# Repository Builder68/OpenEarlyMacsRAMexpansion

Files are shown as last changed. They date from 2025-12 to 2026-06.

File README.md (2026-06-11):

# Open Early Macs RAM Expansion
#
 ## SUMMARY

This upgrade utilizes 1Mb x 16-bit RAM ICs with 1024 refresh cycles, providing up to 4MB of RAM for Macintosh 128K and 512K equipped with the 128KB ROM (Macintosh Plus ROM). 
Testing has confirmed compatibility with a Macintosh 512Ke, including concurrent use with the ROM-INATOR board. Furthermore, installing this memory expansion alongside a SCSI card (like the MacSnap SCSI) enables the 128KB ROM to identify the machine as a Mac Plus.

*Attention: Due to the way the ROM-INATOR board determines the Mac model it's installed on (Mac Plus or Mac 512Ke), its ROM image needs to be [patched](https://68kmla.org/bb/index.php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) before installing this RAM expansion board or any other RAM upgrade.*

## PROJECT STATUS

This project is fully functional on a Mac 512Ke. Although it's expected to work on Mac 128K or 512K systems with the 128KB ROM, this specific compatibility hasn't been tested yet.

## KEY FEATURES

* One single detachable RAM board, which taps several signals through bodge wires with JST connectors and either piggyback sockets or pin headers soldered to components on the LB.
* You can disable RAM expansion through DIP switches on the board.
* A solder jumper allows you to select between two memory size configurations: 2MB or 4MB.
* Compatible with FPM or EDO CMOS RAM ICs of 1Mb x 16 bits.
* The PCB dimensions are designed to allow concurrent installation with [Demik's MacSnap SCSI replica board](https://github.com/demik/MacSnap-SCSI//). 
* No extensions or additional software are needed; Mac will automatically recognize all the configured RAM upon startup.
## ASSEMBLY

While the assembly process is straightforward, it can be challenging. Reflow soldering, or using solder paste and a heat gun, is highly recommended for the RAM chips and most SMD components. 

Although this might sound highly obvious, I must say it:

Please be sure to get the right schematics for your LB revision.

## SPECIAL THANKS

This project wouldn't be where it is today without the significant contributions of Golden Potato. His collaboration on developing and testing this design was instrumental. From the beginning, his desire was that this design should be free and open source with both of our names attached to it. 
#
#

### 1. RAM EXPANSION BOARD 
Front



Back



## 2. BOM



#
## 3. BEFORE INSTALLING 

### 3.1 Socket machine headers at RP2 & RP3 

Prior to installing the expansion board, resistor arrays RP2 and RP3 must be removed from the LB and replaced with socket pin machine headers.
#
## 4. INSTALLATION

### 4.1 Pin headers
  
Solder machine pin headers (male to male) onto ICs U12E, U13E, and U4F. Then, the board connects to these pin headers via sockets soldered on the backside of the expansion board.

Optionally, you can instead solder DIP sockets onto U12E, U13E, and U4F (piggybacked) and solder male-to-male pin headers to the expansion board.

## 5. Signals to JST connectors

The following tables shows the signals that are collected via bodged wires from the LB to the JST connectors J11 and J12:

### 5.1 J11

| SIGNAL | Location | Pin N° | Comment |
|:---:|:---:|:---:|:---:|
| /SNDPG2 |Pin N°5 - U2F |1 | |
| /DMA |Pin N°15 - U2F  |2 | |
| VA6 |Pin N°6 - U2F |3 | |
| VA13 |Pin N°12 - U3G  |4 | |
| A18 |Pin N°46 - CPU  |5 | |
| VA5 |Pin N°13 - U3G  |6 | |

### 5.2 J12

| SIGNAL | Location on LB | Pin N° | Comment |
|:---:|:---:|:---:|:---:|
| A17 |Pin N°45 - CPU |1 | |
| A20 |Pin N°5 - U4D |2 | |
| A19 |Pin N°3 - U3D |3 | |
| A21 |Pin N°50 - CPU |4 | |
| /RAS |Left Leg of R4 or Pin N°14 - 4D |5 | | 
| R/WF |Right Leg of R33  |6 | |
#

LB Signals to RAM Card

## 6. SETTINGS

### 6.1 RAM Expansion Board

#### 6.1.1 IC RAM Type (FPM / EDO)

Solder jumpers JP1 & JP2 selects between FPM or EDO RAM IC types

#### 6.1.2 RAM Size

|JP3 |RAM Size |
|:---:|:---:|
| 2-3 | 2MB |
| 1-2. | 4MB. |

#### 6.1.3 RAM Expansion Enabling (SWB1 & SWB2)

SWB1
|S n°|Expansion RAM Enabled  |  Expansion RAM Disabled |
|:--:|:---:|:---:|
| 1  | ON | OFF |
| 2  | OFF | ON |
| 3  | ON | OFF |
| 4  | OFF | ON |
| 5  | ON | OFF |
| 6  | OFF | ON |

SWB2
|S n°|Expansion RAM Enabled  |  Expansion RAM Disabled |
|:--:|:---:|:---:|
| 1  | ON | OFF |
| 2  | OFF | ON |
| 3  | ON | OFF |
| 4  | OFF | ON |
| 5  | ON | OFF |
| 6  | ON | OFF |
| 7  | OFF | ON |
| 8  | OFF | ON |

*Attention: double check all connections and DIP switch settings before power-up*

Good luck. Let us know how it goes here: https://68kmla.org/bb/index.php?threads/early-macintosh-home-brew-4mb-memory-upgrade-board-development.47308/

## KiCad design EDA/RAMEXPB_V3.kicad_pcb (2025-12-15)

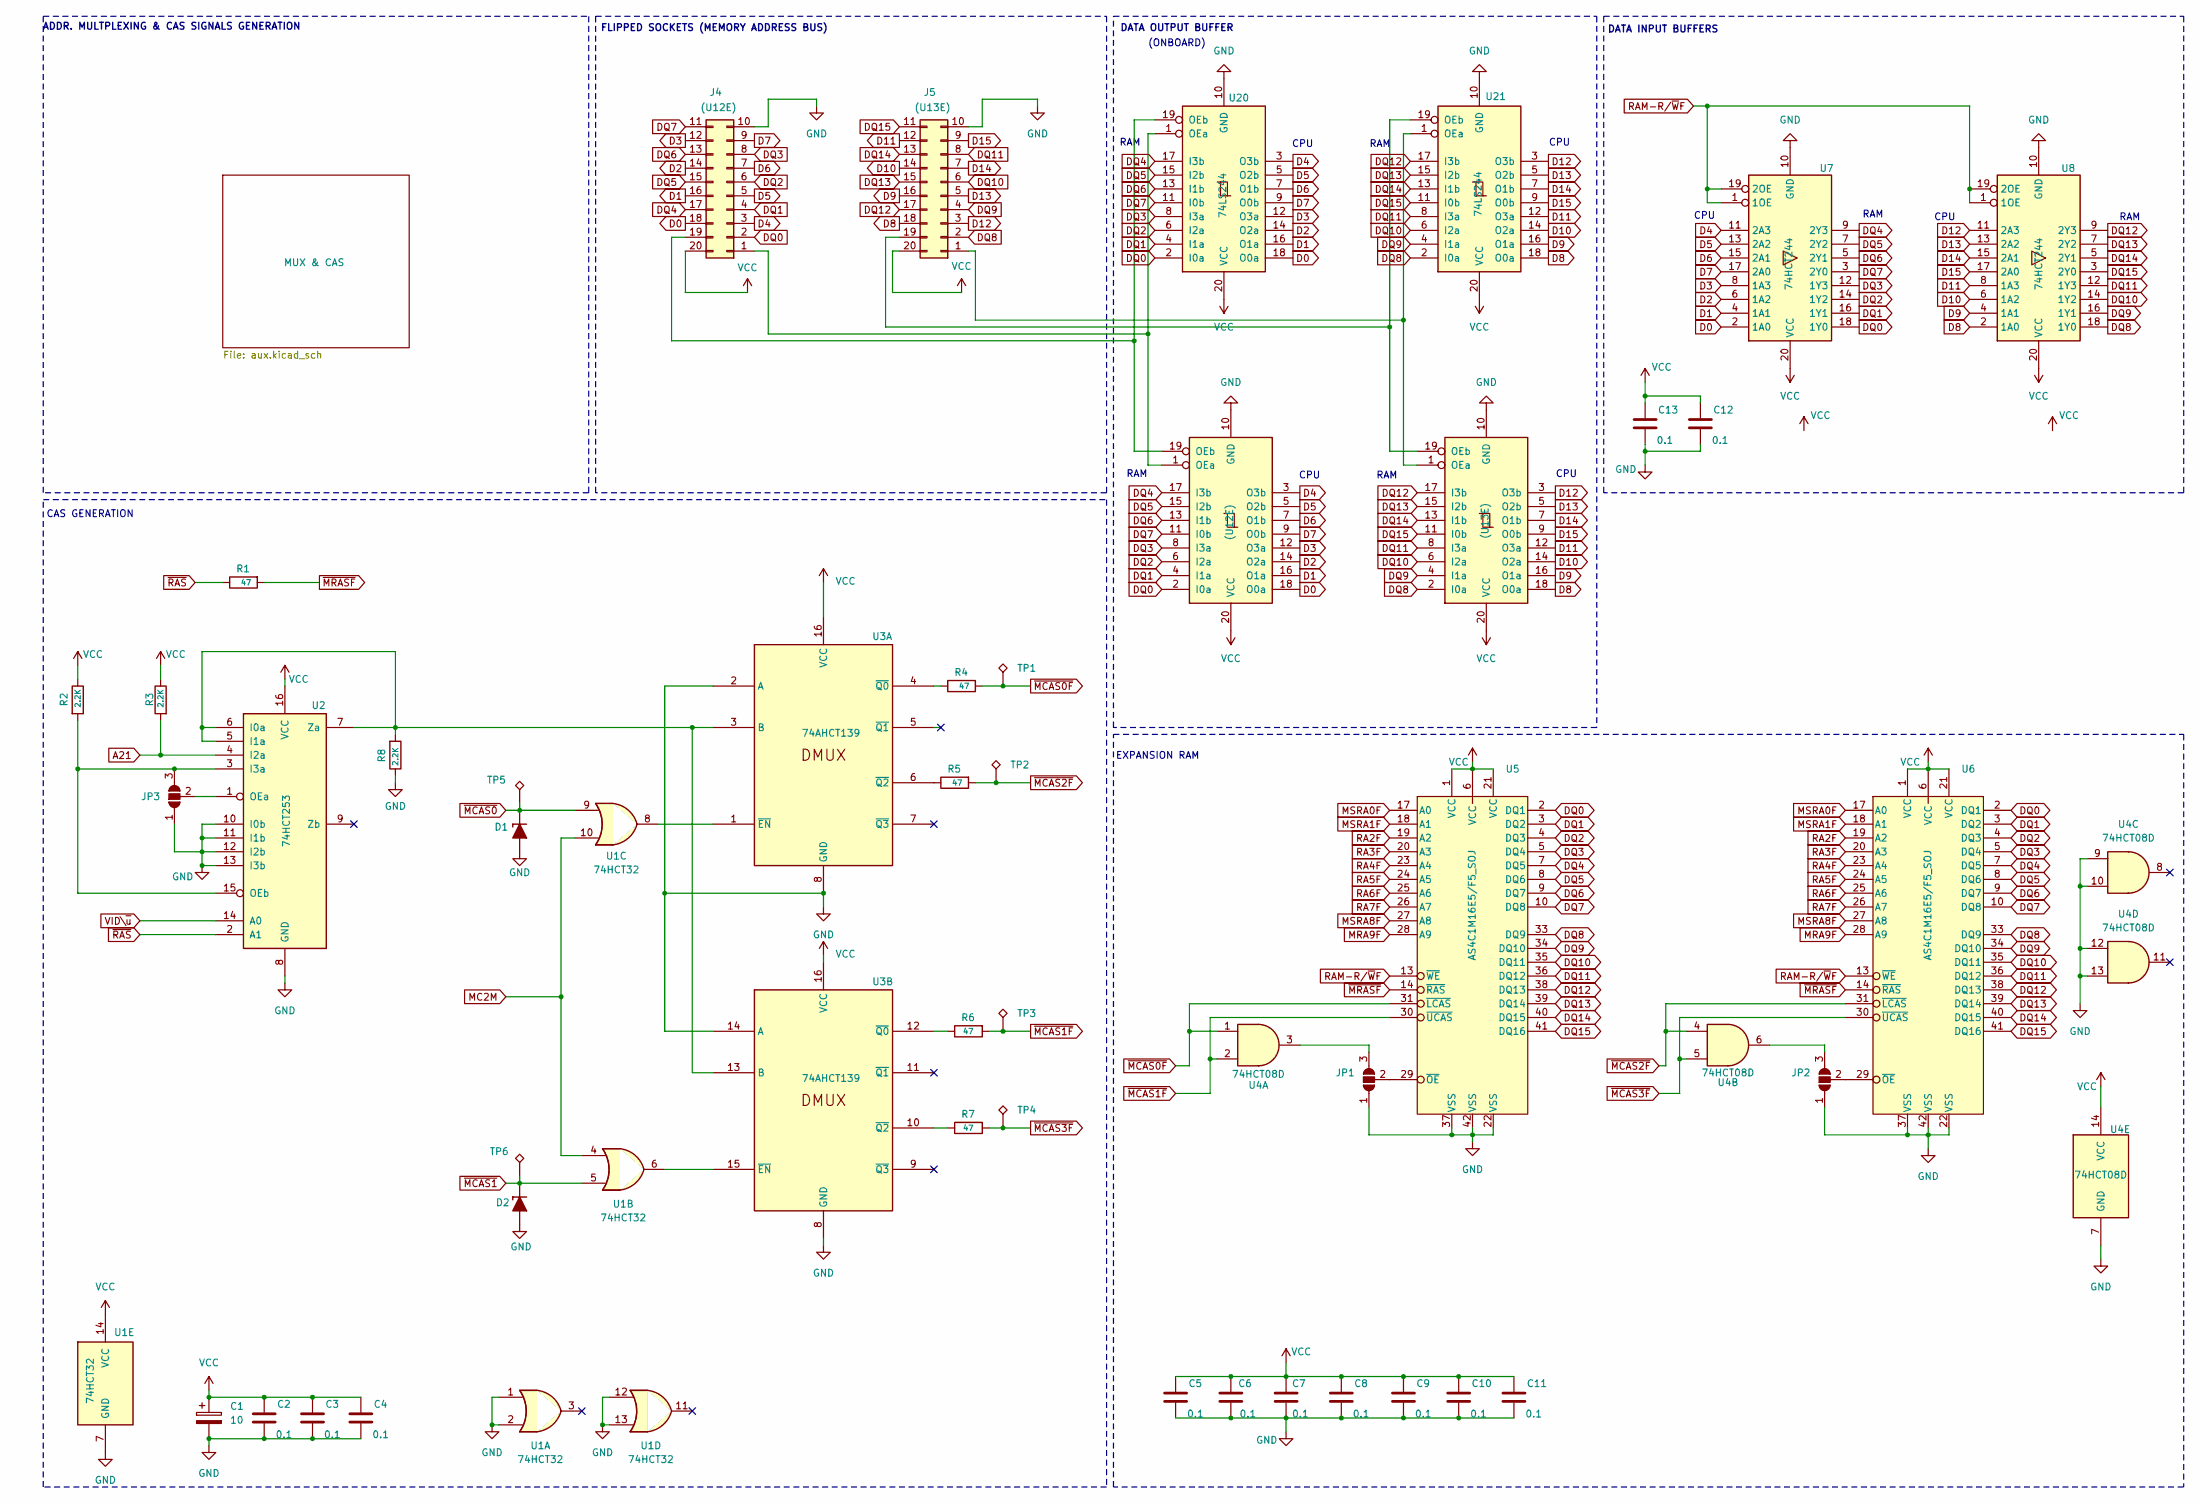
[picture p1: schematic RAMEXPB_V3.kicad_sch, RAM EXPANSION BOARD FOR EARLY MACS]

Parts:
C1: 10; CP_EIA-6032-28_Kemet-C_Pad2.25x2.35mm_HandSolder
C2, C3, C4, C5, C6, C7, C8, C9, C10, C11, C12, C13: 0.1; C_0805_2012Metric_Pad1.18x1.45mm_HandSolder
D1, D2: SZMMSZ5V1T1G; D_SOD-123
J4: (U12E); DIP-20_Socket_INV_Flip
J5: (U13E); DIP-20_Socket_INV_Flip
JP1, JP2, JP3: SolderJumper_3_Open; SolderJumper-3_P1.3mm_Open_RoundedPad1.0x1.5mm_NumberLabels
R1, R4, R5, R6, R7: 47; R_0805_2012Metric_Pad1.20x1.40mm_HandSolder
R2, R3, R8: 2.2K; R_0805_2012Metric_Pad1.20x1.40mm_HandSolder
TP1, TP2, TP3, TP4, TP5, TP6: TestPoint_Alt; TestPoint_Pad_D1.0mm
U1: 74HCT32; SO-14_3.9x8.65mm_P1.27mm
U2: 74HCT253; SO-16_3.9x9.9mm_P1.27mm
U3: 74AHCT139; SO-16_3.9x9.9mm_P1.27mm
U4: 74HCT08D; SO-14_3.9x8.65mm_P1.27mm
U5, U6: AS4C1M16E5/F5_SOJ; SOJ-42_400mil
U7, U8: 74HCT244; SOIC-20W_7.5x12.8mm_P1.27mm
U12: (U12E); DIP-20_W7.62mm_Socket
U13: (U13E); DIP-20_W7.62mm_Socket
U20, U21: 74LS244; Socket_DIP-20_7.62mm_Conn_Hole1mm_custom

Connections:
A21: R3.2, U2.4 (I2a); also elsewhere on the board
D0: J4.18, U7.2 (1A0), U12.18 (O0a), U20.18 (O0a)
D1: J4.16, U7.4 (1A1), U12.16 (O1a), U20.16 (O1a)
D2: J4.14, U7.6 (1A2), U12.14 (O2a), U20.14 (O2a)
D3: J4.12, U7.8 (1A3), U12.12 (O3a), U20.12 (O3a)
D4: J4.3, U7.11 (2A3), U12.3 (O3b), U20.3 (O3b)
D5: J4.5, U7.13 (2A2), U12.5 (O2b), U20.5 (O2b)
D6: J4.7, U7.15 (2A1), U12.7 (O1b), U20.7 (O1b)
D7: J4.9, U7.17 (2A0), U12.9 (O0b), U20.9 (O0b)
D8: J5.18, U8.2 (1A0), U13.18 (O0a), U21.18 (O0a)
D9: J5.16, U8.4 (1A1), U13.16 (O1a), U21.16 (O1a)
D10: J5.14, U8.6 (1A2), U13.14 (O2a), U21.14 (O2a)
D11: J5.12, U8.8 (1A3), U13.12 (O3a), U21.12 (O3a)
D12: J5.3, U8.11 (2A3), U13.3 (O3b), U21.3 (O3b)
D13: J5.5, U8.13 (2A2), U13.5 (O2b), U21.5 (O2b)
D14: J5.7, U8.15 (2A1), U13.7 (O1b), U21.7 (O1b)
D15: J5.9, U8.17 (2A0), U13.9 (O0b), U21.9 (O0b)
DQ0: J4.2, U5.2 (DQ1), U6.2 (DQ1), U7.18 (1Y0), U12.2 (I0a), U20.2 (I0a)
DQ1: J4.4, U5.3 (DQ2), U6.3 (DQ2), U7.16 (1Y1), U12.4 (I1a), U20.4 (I1a)
DQ2: J4.6, U5.4 (DQ3), U6.4 (DQ3), U7.14 (1Y2), U12.6 (I2a), U20.6 (I2a)
DQ3: J4.8, U5.5 (DQ4), U6.5 (DQ4), U7.12 (1Y3), U12.8 (I3a), U20.8 (I3a)
DQ4: J4.17, U5.7 (DQ5), U6.7 (DQ5), U7.9 (2Y3), U12.17 (I3b), U20.17 (I3b)
DQ5: J4.15, U5.8 (DQ6), U6.8 (DQ6), U7.7 (2Y2), U12.15 (I2b), U20.15 (I2b)
DQ6: J4.13, U5.9 (DQ7), U6.9 (DQ7), U7.5 (2Y1), U12.13 (I1b), U20.13 (I1b)
DQ7: J4.11, U5.10 (DQ8), U6.10 (DQ8), U7.3 (2Y0), U12.11 (I0b), U20.11 (I0b)
DQ8: J5.2, U5.33 (DQ9), U6.33 (DQ9), U8.18 (1Y0), U13.2 (I0a), U21.2 (I0a)
DQ9: J5.4, U5.34 (DQ10), U6.34 (DQ10), U8.16 (1Y1), U13.4 (I1a), U21.4 (I1a)
DQ10: J5.6, U5.35 (DQ11), U6.35 (DQ11), U8.14 (1Y2), U13.6 (I2a), U21.6 (I2a)
DQ11: J5.8, U5.36 (DQ12), U6.36 (DQ12), U8.12 (1Y3), U13.8 (I3a), U21.8 (I3a)
DQ12: J5.17, U5.38 (DQ13), U6.38 (DQ13), U8.9 (2Y3), U13.17 (I3b), U21.17 (I3b)
DQ13: J5.15, U5.39 (DQ14), U6.39 (DQ14), U8.7 (2Y2), U13.15 (I2b), U21.15 (I2b)
DQ14: J5.13, U5.40 (DQ15), U6.40 (DQ15), U8.5 (2Y1), U13.13 (I1b), U21.13 (I1b)
DQ15: J5.11, U5.41 (DQ16), U6.41 (DQ16), U8.3 (2Y0), U13.11 (I0b), U21.11 (I0b)
GND: C1.2, C2.2, C3.2, C4.2, C5.2, C6.2, C7.2, C8.2, C9.2, C10.2, C11.2, C12.2, C13.2, D1.2 (A), D2.2 (A), J4.10, J5.10, JP1.1 (A), JP2.1 (A), JP3.1 (A), R8.1, U1.1, U1.2, U1.7 (GND), U1.12, U1.13, U2.8 (GND), U2.10 (I0b), U2.11 (I1b), U2.12 (I2b), U2.13 (I3b), U3.2 (A), U3.8 (GND), U3.14 (A), U4.7 (GND), U4.9, U4.10, U4.12, U4.13, U5.22 (VSS), U5.37 (VSS), U5.42 (VSS), U6.22 (VSS), U6.37 (VSS), U6.42 (VSS), U7.10 (GND), U8.10 (GND), U12.10 (GND), U13.10 (GND), U20.10 (GND), U21.10 (GND); also elsewhere on the board
MC2M: U1.4, U1.10; also elsewhere on the board
MRA9F: U5.28 (A9), U6.28 (A9); also elsewhere on the board
MSRA0F: U5.17 (A0), U6.17 (A0); also elsewhere on the board
MSRA1F: U5.18 (A1), U6.18 (A1); also elsewhere on the board
MSRA8F: U5.27 (A8), U6.27 (A8); also elsewhere on the board
unnamed: J4.1, U12.1 (OEa), U20.1 (OEa)
unnamed: J4.19, U12.19 (OEb), U20.19 (OEb)
unnamed: J5.1, U13.1 (OEa), U21.1 (OEa)
unnamed: J5.19, U13.19 (OEb), U21.19 (OEb)
unnamed: JP1.3 (B), U4.3
unnamed: JP1.2 (C), U5.29 (~OE)
unnamed: JP2.3 (B), U4.6
unnamed: JP2.2 (C), U6.29 (~OE)
unnamed: JP3.3 (B), R2.2, U2.3 (I3a), U2.15 (OEb)
unnamed: JP3.2 (C), U2.1 (OEa)
unnamed: R8.2, U2.5 (I1a), U2.6 (I0a), U2.7 (Za), U3.3 (B), U3.13 (B)
unnamed: U1.8, U3.1 (~EN)
unnamed: R4.1, U3.4 (~Q0)
unnamed: R5.1, U3.6 (~Q2)
unnamed: U1.6, U3.15 (~EN)
unnamed: R6.1, U3.12 (~Q0)
unnamed: R7.1, U3.10 (~Q2)
RA2F: U5.19 (A2), U6.19 (A2); also elsewhere on the board
RA3F: U5.20 (A3), U6.20 (A3); also elsewhere on the board
RA4F: U5.23 (A4), U6.23 (A4); also elsewhere on the board
RA5F: U5.24 (A5), U6.24 (A5); also elsewhere on the board
RA6F: U5.25 (A6), U6.25 (A6); also elsewhere on the board
RA7F: U5.26 (A7), U6.26 (A7); also elsewhere on the board
RAM-R/~WF: U5.13 (~WE), U6.13 (~WE), U7.1 (1OE), U7.19 (2OE), U8.1 (1OE), U8.19 (2OE); also elsewhere on the board
VCC: C1.1, C2.1, C3.1, C4.1, C5.1, C6.1, C7.1, C8.1, C9.1, C10.1, C11.1, C12.1, C13.1, J4.20, J5.20, R2.1, R3.1, U1.14 (VCC), U2.16 (VCC), U3.16 (VCC), U4.14 (VCC), U5.1 (VCC), U5.6 (VCC), U5.21 (VCC), U6.1 (VCC), U6.6 (VCC), U6.21 (VCC), U7.20 (VCC), U8.20 (VCC), U12.20 (VCC), U13.20 (VCC), U20.20 (VCC), U21.20 (VCC); also elsewhere on the board
VID\~u: U2.14 (A0); also elsewhere on the board
~MCAS0F: R4.2, TP1.1, U4.1, U5.31 (~LCAS)
~MCAS0: D1.1 (K), TP5.1, U1.9; also elsewhere on the board
~MCAS1F: R6.2, TP3.1, U4.2, U5.30 (~UCAS)
~MCAS1: D2.1 (K), TP6.1, U1.5; also elsewhere on the board
~MCAS2F: R5.2, TP2.1, U4.4, U6.31 (~LCAS)
~MCAS3F: R7.2, TP4.1, U4.5, U6.30 (~UCAS)
~MRASF: R1.2, U5.14 (~RAS), U6.14 (~RAS)
~RAS: R1.1, U2.2 (A1); also elsewhere on the board

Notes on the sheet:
RAM
CPU
DATA INPUT BUFFERS
EXPANSION RAM
DATA OUTPUT BUFFER
CAS GENERATION
FLIPPED SOCKETS (MEMORY ADDRESS BUS)
(ONBOARD)
ADDR. MULTPLEXING & CAS SIGNALS GENERATION

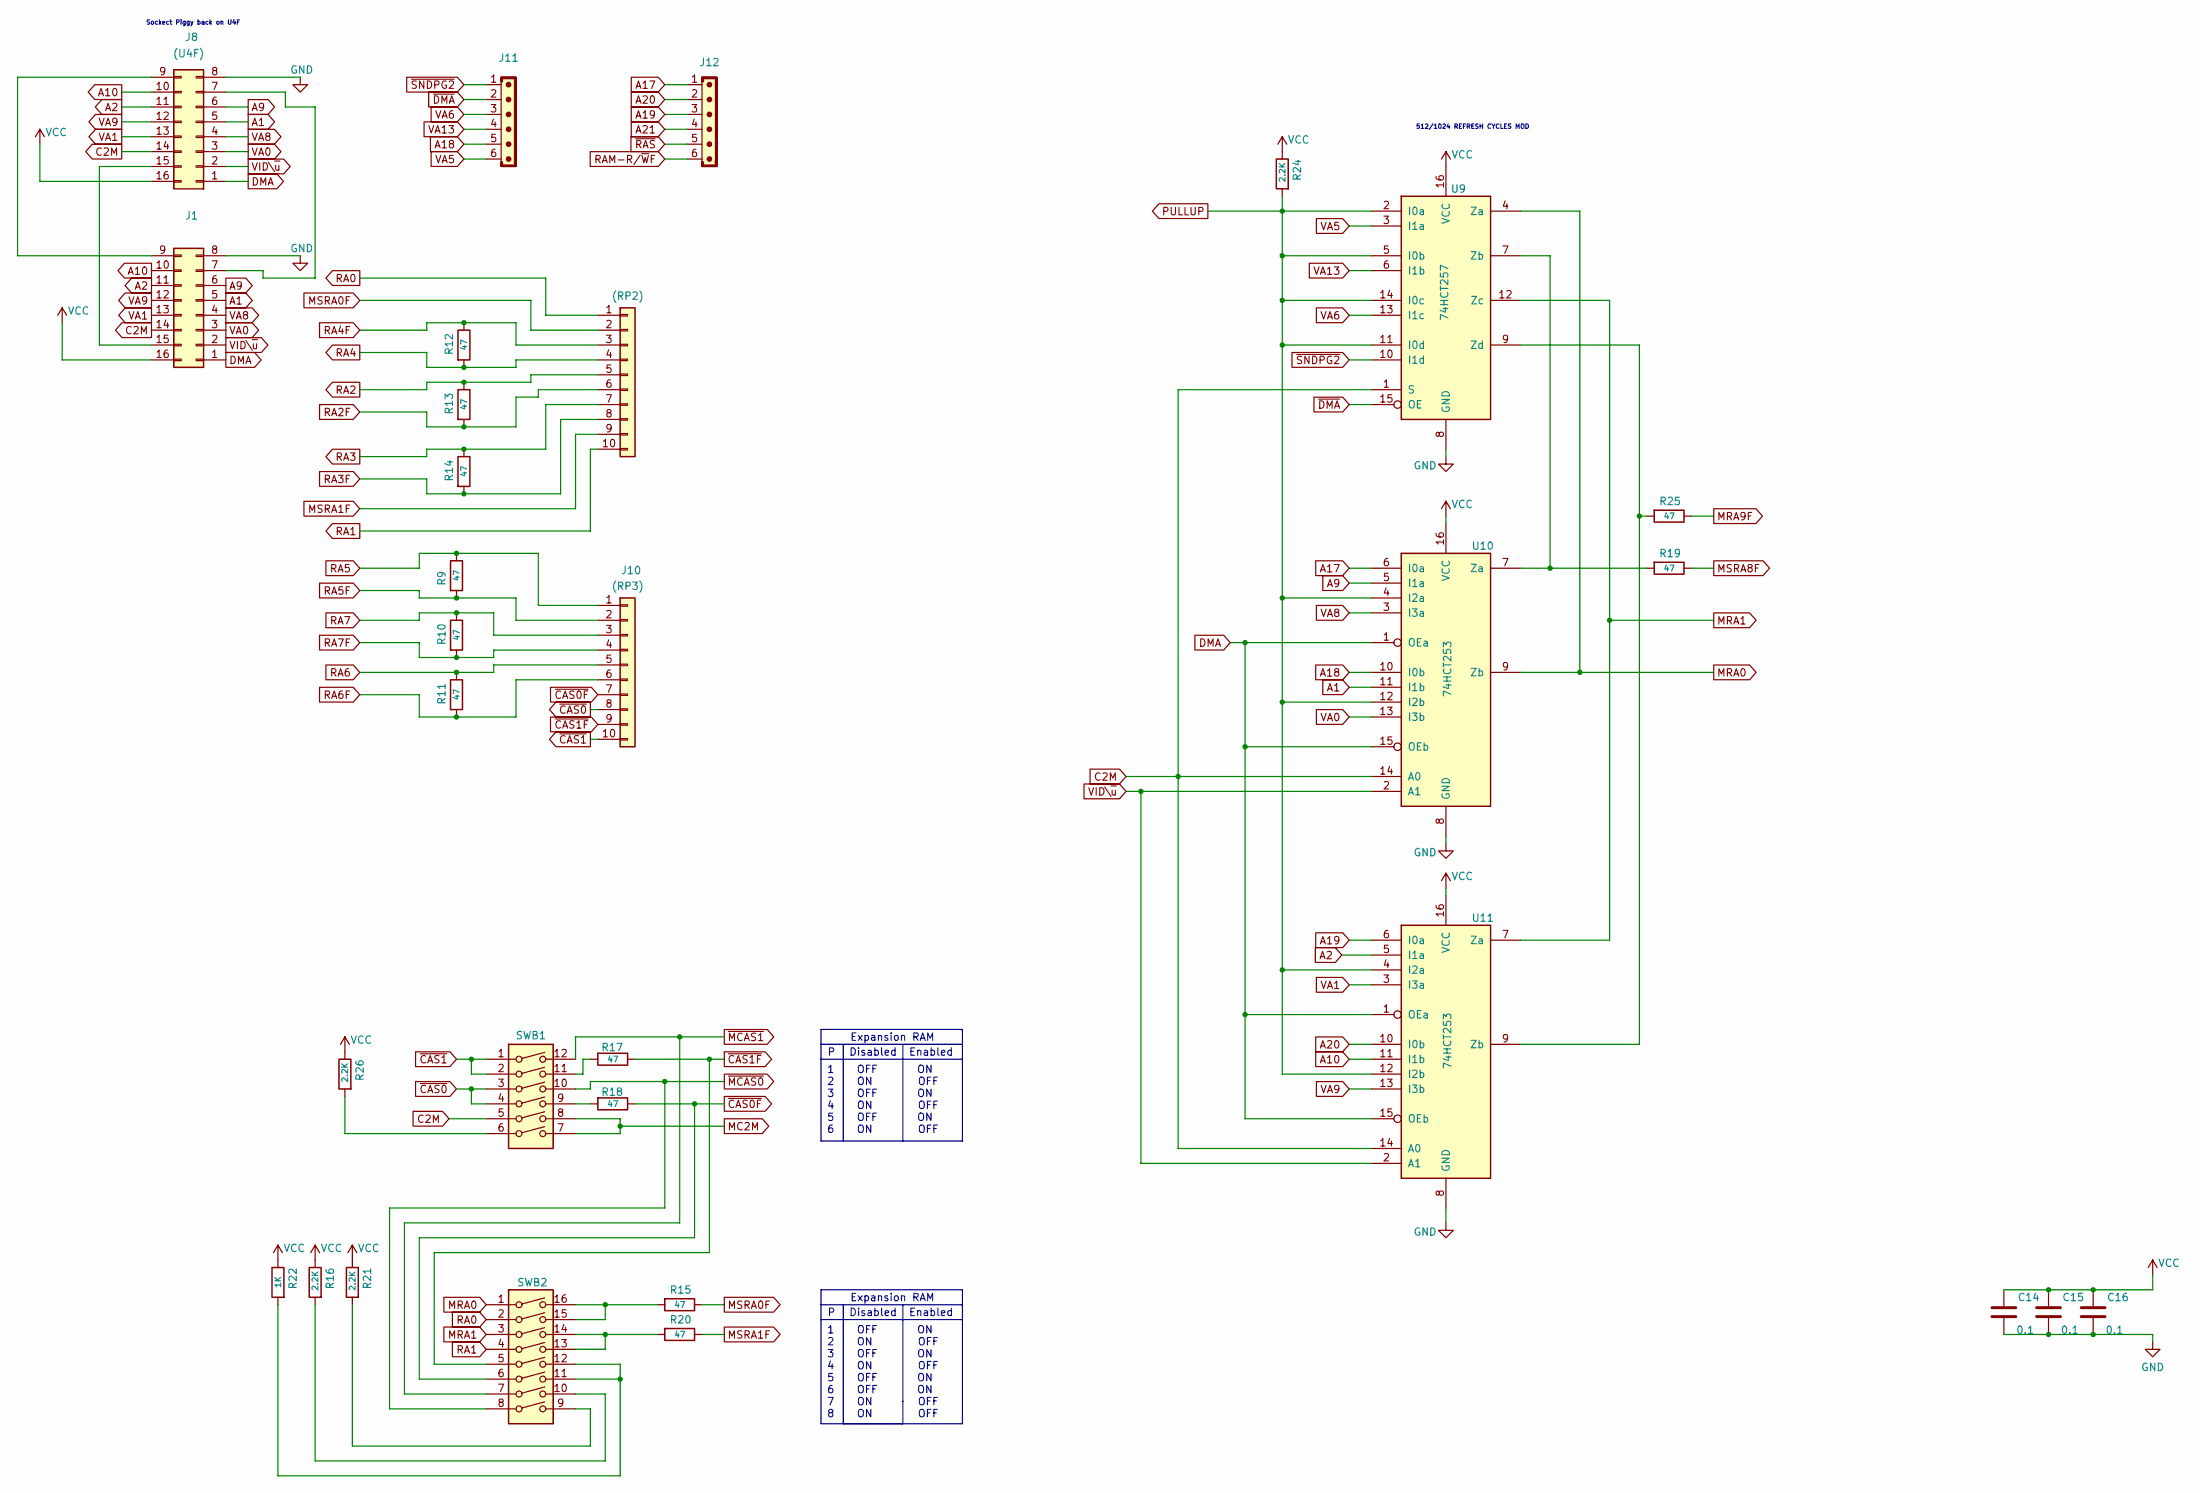
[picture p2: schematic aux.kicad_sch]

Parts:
C14, C15, C16: 0.1; C_0805_2012Metric_Pad1.18x1.45mm_HandSolder
J1: (U4F); DIP-16_W7.62mm_Socket
J8: (U4F); DIP-16_INVERTED_FLIP
J9: (RP2); PinHeader_1x10_P2.54mm_Vertical
J10: (RP3); PinHeader_1x10_P2.54mm_Vertical
J11, J12: JST_06; JST_PH_S6B-PH-K_1x06_P2.00mm_Horizontal
R9, R10, R11, R12, R13, R14, R15, R17, R18, R19, R20, R25: 47; R_0805_2012Metric_Pad1.20x1.40mm_HandSolder
R16, R21, R24, R26: 2.2K; R_0805_2012Metric_Pad1.20x1.40mm_HandSolder
R22: 1K; R_0805_2012Metric_Pad1.20x1.40mm_HandSolder
SWB1: SW_DIP_x06; SW_DIP_SPSTx06_Slide_Omron_A6H-6101_W6.15mm_P1.27mm
SWB2: SW_DIP_x08; SW_DIP_SPSTx08_Slide_Omron_A6H-8101_W6.15mm_P1.27mm
U9: 74HCT257; SO-16_3.9x9.9mm_P1.27mm
U10, U11: 74HCT253; SO-16_3.9x9.9mm_P1.27mm

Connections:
A1: J1.5, J8.5, U10.11 (I1b)
A2: J1.11, J8.11, U11.5 (I1a)
A9: J1.6, J8.6, U10.5 (I1a)
A10: J1.10, J8.10, U11.11 (I1b)
A17: J12.1, U10.6 (I0a)
A18: J11.5, U10.10 (I0b)
A19: J12.3, U11.6 (I0a)
A20: J12.2, U11.10 (I0b)
A21: J12.4; also elsewhere on the board
C2M: J1.14, J8.14, SWB1.5, U9.1 (S), U10.14 (A0), U11.14 (A0)
DMA: J1.1, J8.1, U10.1 (OEa), U10.15 (OEb), U11.1 (OEa), U11.15 (OEb)
GND: C14.2, C15.2, C16.2, J1.8, J8.8, U9.8 (GND), U10.8 (GND), U11.8 (GND); also elsewhere on the board
MC2M: SWB1.7, SWB1.8; also elsewhere on the board
MRA0: SWB2.1, U9.4 (Za), U10.9 (Zb)
MRA1: SWB2.3, U9.12 (Zc), U11.7 (Za)
MRA9F: R25.1; also elsewhere on the board
MSRA0F: J9.2, R15.1; also elsewhere on the board
MSRA1F: J9.9, R20.1; also elsewhere on the board
MSRA8F: R19.1; also elsewhere on the board
unnamed: J1.7, J8.7
unnamed: J1.9, J8.9
unnamed: J1.15, J8.15
unnamed: R15.2, SWB2.15, SWB2.16
unnamed: R16.2, SWB2.10
unnamed: R17.2, SWB1.11
unnamed: R18.2, SWB1.9
unnamed: R20.2, SWB2.13, SWB2.14
unnamed: R21.2, SWB2.9
unnamed: R22.2, SWB2.11, SWB2.12
unnamed: R26.2, SWB1.6
unnamed: R19.2, U9.7 (Zb), U10.7 (Za)
unnamed: R25.2, U9.9 (Zd), U11.9 (Zb)
PULLUP: R24.2, U9.2 (I0a), U9.5 (I0b), U9.11 (I0d), U9.14 (I0c), U10.4 (I2a), U10.12 (I2b), U11.4 (I2a), U11.12 (I2b)
RA0: J9.1, SWB2.2
RA1: J9.10, SWB2.4
RA2: J9.5, R13.1
RA2F: J9.6, R13.2; also elsewhere on the board
RA3: J9.7, R14.1
RA3F: J9.8, R14.2; also elsewhere on the board
RA4: J9.4, R12.2
RA4F: J9.3, R12.1; also elsewhere on the board
RA5: J10.1, R9.1
RA5F: J10.2, R9.2; also elsewhere on the board
RA6: J10.5, R11.1
RA6F: J10.6, R11.2; also elsewhere on the board
RA7: J10.3, R10.1
RA7F: J10.4, R10.2; also elsewhere on the board
RAM-R/~WF: J12.6; also elsewhere on the board
VA0: J1.3, J8.3, U10.13 (I3b)
VA1: J1.13, J8.13, U11.3 (I3a)
VA5: J11.6, U9.3 (I1a)
VA6: J11.3, U9.13 (I1c)
VA8: J1.4, J8.4, U10.3 (I3a)
VA9: J1.12, J8.12, U11.13 (I3b)
VA13: J11.4, U9.6 (I1b)
VCC: C14.1, C15.1, C16.1, J1.16, J8.16, R16.1, R21.1, R22.1, R24.1, R26.1, U9.16 (VCC), U10.16 (VCC), U11.16 (VCC); also elsewhere on the board
VID\~u: J1.2, J8.2, U10.2 (A1), U11.2 (A1); also elsewhere on the board
~CAS0F: J10.7, R18.1, SWB2.6
~CAS0: J10.8, SWB1.3, SWB1.4
~CAS1F: J10.9, R17.1, SWB2.5
~CAS1: J10.10, SWB1.1, SWB1.2
~DMA: J11.2, U9.15 (OE)
~MCAS0: SWB1.10, SWB2.8; also elsewhere on the board
~MCAS1: SWB1.12, SWB2.7; also elsewhere on the board
~RAS: J12.5; also elsewhere on the board
~SNDPG2: J11.1, U9.10 (I1d)

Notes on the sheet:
Sockect Piggy back on U4F
Disabled
Enabled
Expansion RAM
512/1024 REFRESH CYCLES MOD
1 OFF ON 2 ON OFF 3 OFF ON 4 ON OFF 5 OFF ON 6 OFF ON 7 ON OFF 8 ON OFF
1 OFF ON 2 ON OFF 3 OFF ON 4 ON OFF 5 OFF ON 6 ON OFF

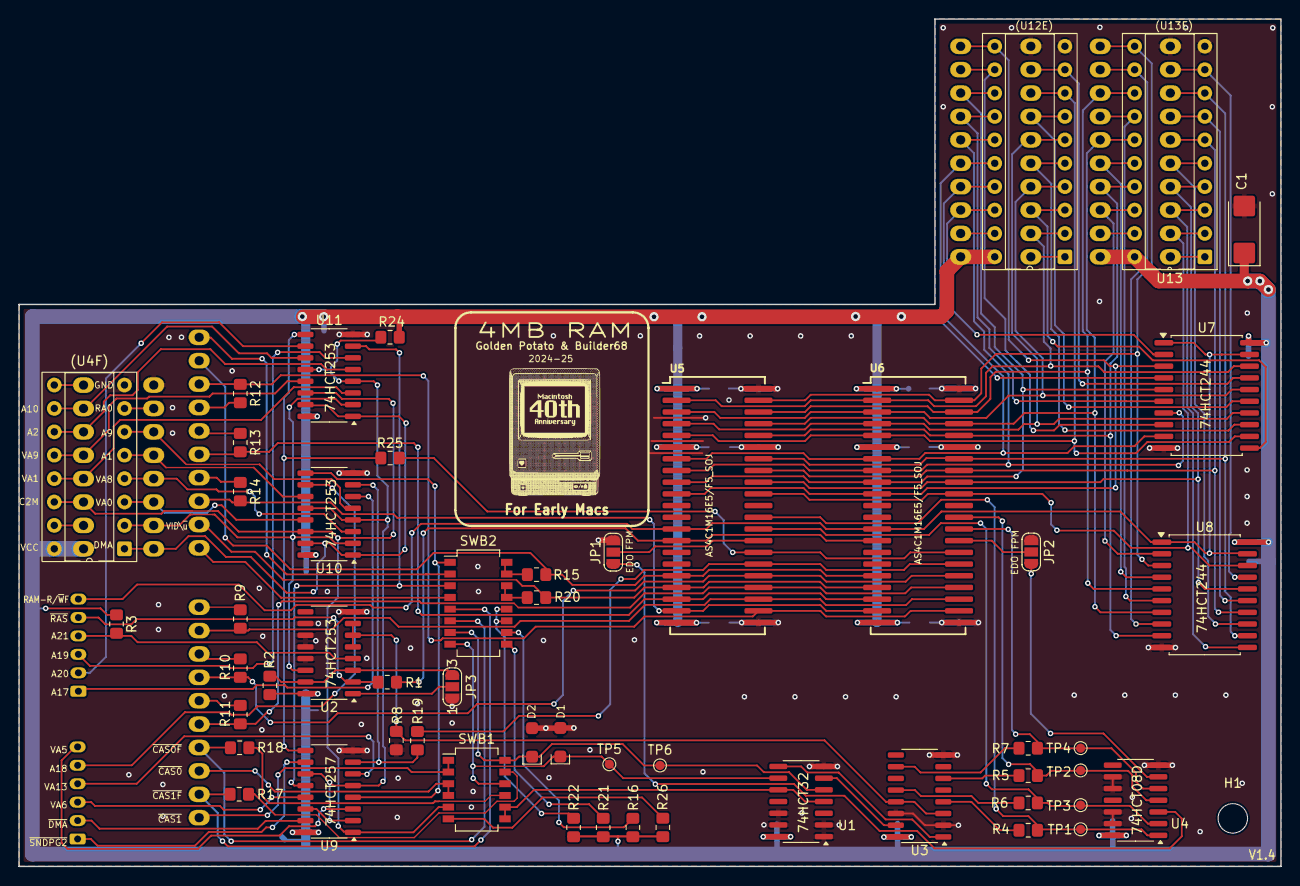
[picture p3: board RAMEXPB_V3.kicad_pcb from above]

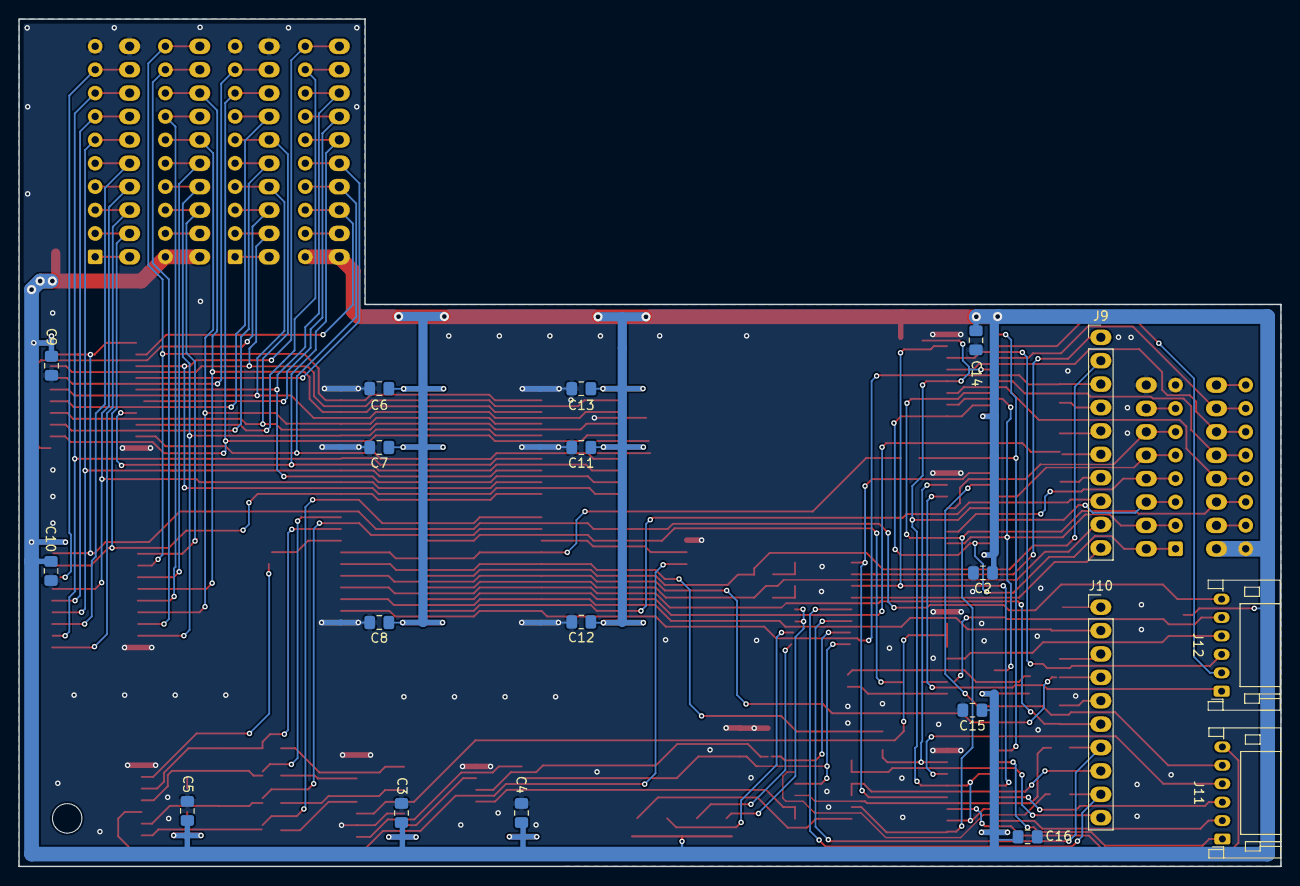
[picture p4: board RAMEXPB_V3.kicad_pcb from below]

Board: 2 copper layers, 137.0 x 92.0 mm, 76 parts (22 on the bottom side), 120 nets.

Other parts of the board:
H1: M3_Spacer_H12.7mm; MountingHole_3.2mm_M3_DIN965

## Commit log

2024-11-12 Add files via upload
    Auxiliary Board V2 Gerber Files
2024-11-24 RAM Expansion PCB version 2.1
    Updated PCB design to provide adequate clearance for the integration of a MacSnap SCSI board. No functional changes to the core circuitry.
    [RAMEXB_V21_Github-B_Cu.gbr, RAMEXB_V21_Github-B_Mask.gbr, RAMEXB_V21_Github-B_Paste.gbr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]
2024-11-24 Add files via upload
    Interactive HTML BOM
2025-01-09 Add files via upload
    Corrected missing trace to pad #26 on U17 (MSRA8F).
    Fixed legends for SWA1 & RAM settings.
    [RAMEXB_V2_2-B_Paste.gbp, RAMEXB_V2_2-B_Silkscreen.gbo, RAMEXB_V2_2-F_Cu.gtl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]
2025-01-10 Add files via upload
    RAM size settings legend corrected
    [RAMEXB_V2_2-B_Cu.gbl, RAMEXB_V2_2-B_Mask.gbs, RAMEXB_V2_2-B_Silkscreen.gbo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]
2025-01-10 Several fixes
    - Added missing trace from pad 26 on U17 (MSRA8F). System RAM can now be swapped using DIP switches.
    - Corrected the legends for RAM settings and system RAM swapping.
    - Addressed other minor issues in the tracing of some routes.
    [RAMEXB_V2_2-B_Cu.gbl, RAMEXB_V2_2-B_Mask.gbs, RAMEXB_V2_2-B_Paste.gbp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]
2025-05-08 74139 outputs fixed
    [RAMEXPB_V3.kicad_pcb]
2025-12-15 PCB V1.4
    [RAMEXPB_V3-B_Cu.gbr, RAMEXPB_V3-B_Mask.gbr, RAMEXPB_V3-B_Paste.gbr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]
2025-12-15 Add files via upload
    PCB V1.4
2025-12-15 Update RAM Expansion Board images in README

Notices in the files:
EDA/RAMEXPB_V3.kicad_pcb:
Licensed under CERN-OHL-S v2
